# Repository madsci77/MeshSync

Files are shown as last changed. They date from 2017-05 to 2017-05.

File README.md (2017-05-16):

# MeshSync
A simple mobile ad hoc network designed to synchronize EL wire or LEDs on Burning Man costumes

I created this project back in 2012 with the goal of building a low cost device (around USD $10) that would plug in between a user's EL wire inverter and the EL wire on their costume or bike and automatically synchronize flashing patterns with other users around them.

It worked pretty well, but it turned out to be nearly impossible to get enough people together at the same time to do any of the more elaborate patterns.  Around 40 units were built.

Also included is a visual simulator written in VB to test out various aspects of the protocol.  It supports automatic partitioning and merging; if a group splits or multiple groups come together, they will automatically reorganize.  Patterns are chosen that are appropriate for the number of group members.

It's a mesh network and in the pathological case of nodes strung out so that each can only hear one node to either side, it'll still converge within a few network cycles.

Very little data is carried over the network; it's just timing information, group membership, and the currently running pattern.

The lowest hardware ID chooses the pattern.  Hardware ID 0 is reserved for a manual control device with a selector button.  Absent a manual control, patterns are chosen randomly.

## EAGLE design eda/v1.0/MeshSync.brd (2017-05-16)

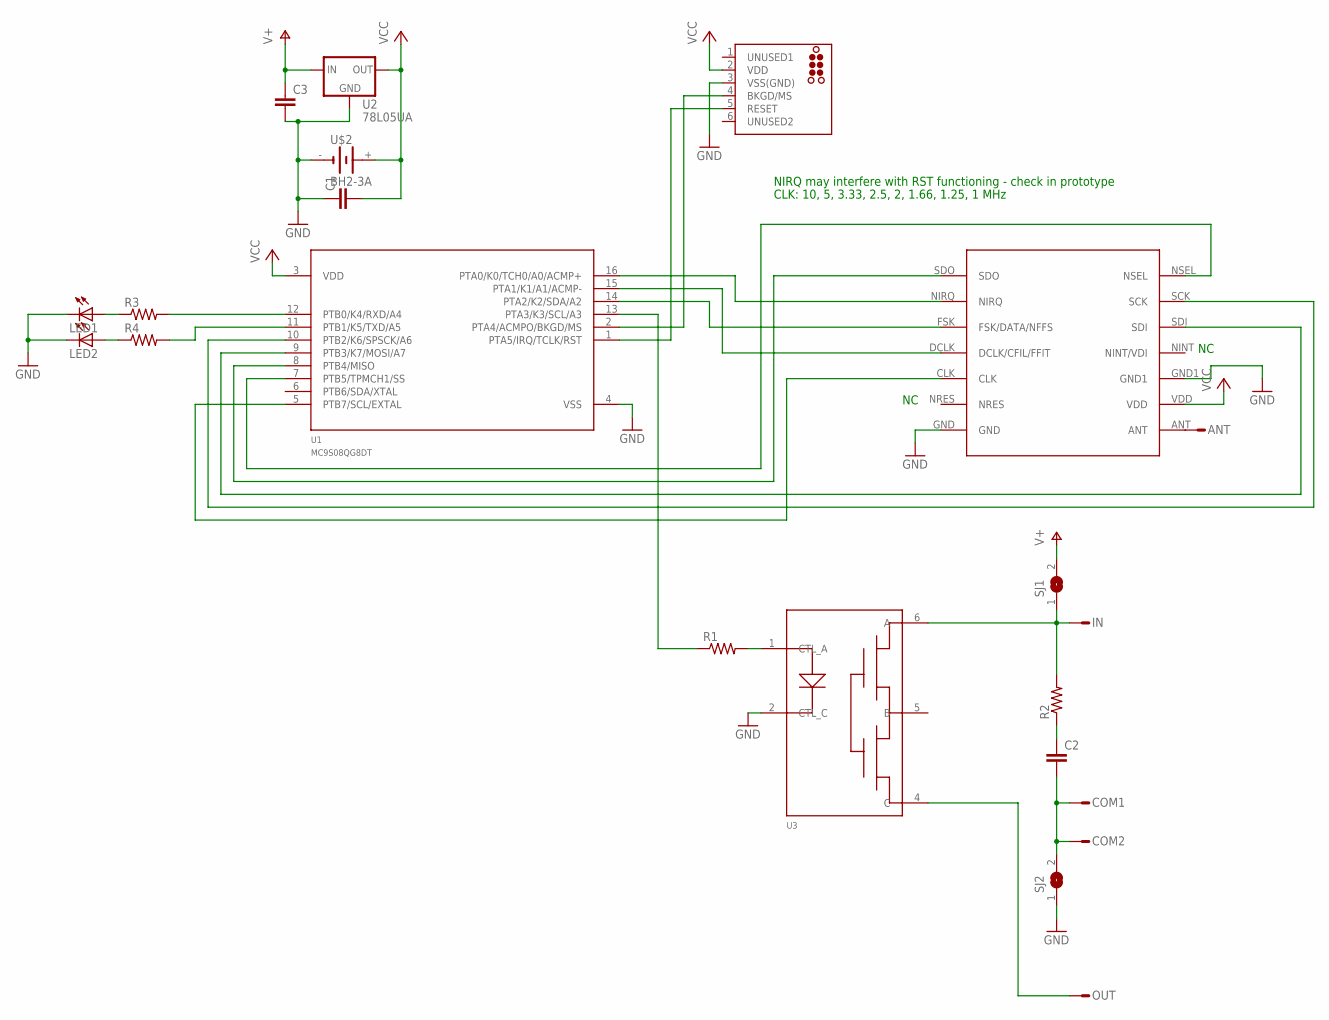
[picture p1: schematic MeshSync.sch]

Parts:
ANT: PIN; PINHEAD-1
C1: C-EUC0805K; C0805K
C2, C3: C-EUC0603K; C0603K
COM1, COM2: PIN; PINHEAD-1
IN: PIN; PINHEAD-1
LED1, LED2: LEDCHIPLED_0603; CHIPLED_0603
OUT: PIN; PINHEAD-1
R1, R2, R3, R4: R0603
SJ1, SJ2: SJW
U1: MC9S08QG8DT; TSSOP16
U2: 78L05UA; SOT89
U3: PVT312; DIL06-SMT
U$1: TC2030-MCP-NL
U$2: BH2-3A
XCVR: RFM12B

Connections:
GND: C1.1, C3.2, LED1.C, LED2.C, SJ2.1, U1.4 (VSS), U2.2 (GND), U3.2 (CTL_C), U$1.3 (VSS(GND)), U$2.-, XCVR.GND, XCVR.GND1
unnamed: U1.2 (PTA4/ACMPO/BKGD/MS), U$1.4 (BKGD/MS)
unnamed: U1.1 (PTA5/IRQ/TCLK/RST), U$1.5 (RESET)
unnamed: R1.2, U3.1 (CTL_A)
unnamed: U1.8 (PTB4/MISO), XCVR.SDO
unnamed: U1.9 (PTB3/K7/MOSI/A7), XCVR.SDI
unnamed: U1.10 (PTB2/K6/SPSCK/A6), XCVR.SCK
unnamed: U1.7 (PTB5/TPMCH1/SS), XCVR.NSEL
unnamed: U1.16 (PTA0/K0/TCH0/A0/ACMP+), XCVR.NIRQ
unnamed: U1.5 (PTB7/SCL/EXTAL), XCVR.CLK
unnamed: U1.15 (PTA1/K1/A1/ACMP-), XCVR.DCLK (DCLK/CFIL/FFIT)
unnamed: U1.14 (PTA2/K2/SDA/A2), XCVR.FSK (FSK/DATA/NFFS)
unnamed: ANT.1, XCVR.ANT
unnamed: R1.1, U1.13 (PTA3/K3/SCL/A3)
unnamed: IN.1, R2.2, SJ1.1, U3.6 (A)
unnamed: OUT.1, U3.4 (C)
unnamed: C2.1, R2.1
unnamed: C2.2, COM1.1, COM2.1, SJ2.2
unnamed: R4.2, U1.11 (PTB1/K5/TXD/A5)
unnamed: R3.2, U1.12 (PTB0/K4/RXD/A4)
unnamed: LED1.A, R3.1
unnamed: LED2.A, R4.1
V+: C3.1, SJ1.2, U2.3 (IN)
VCC: C1.2, U1.3 (VDD), U2.1 (OUT), U$1.2 (VDD), U$2.+, XCVR.VDD

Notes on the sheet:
CLK: 10, 5, 3.33, 2.5, 2, 1.66, 1.25, 1 MHz
NIRQ may interfere with RST functioning - check in prototype

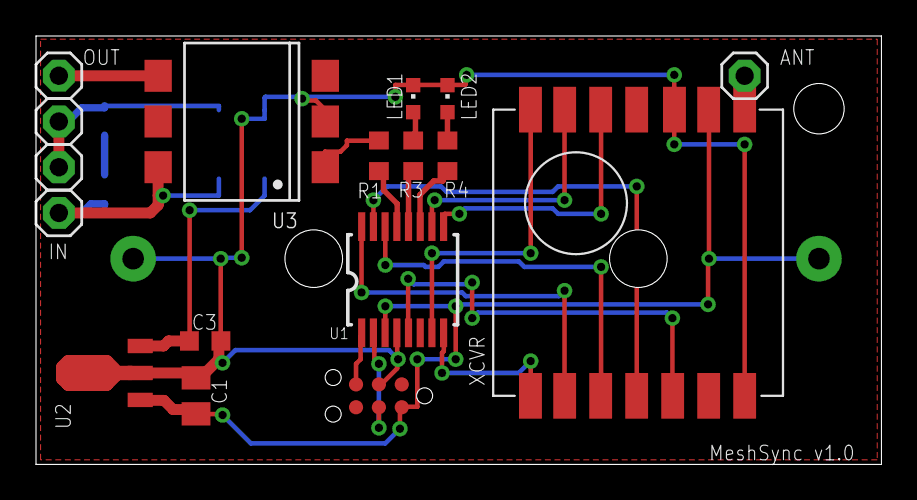
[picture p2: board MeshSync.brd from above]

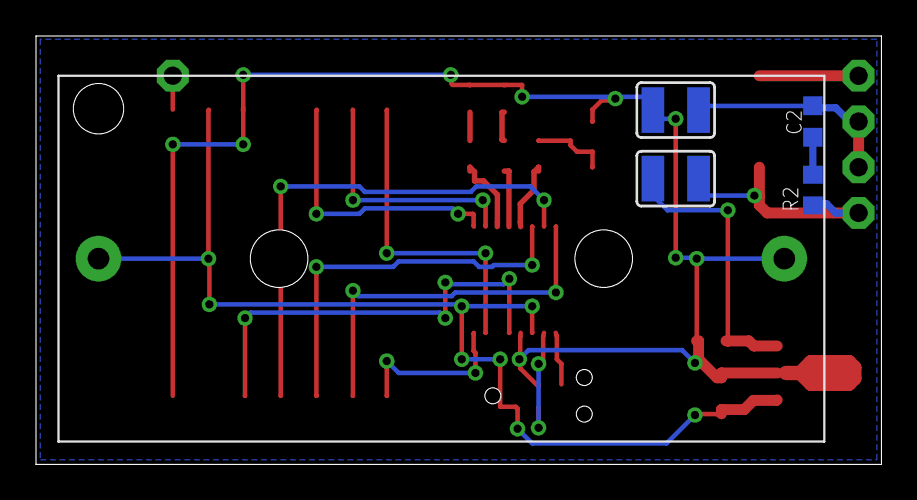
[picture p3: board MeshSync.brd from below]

Board: 2 copper layers, 47.0 x 23.8 mm, 22 parts (5 on the bottom side), 24 nets.

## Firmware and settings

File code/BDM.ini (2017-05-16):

[HI-WAVE]
Target=HCS08ICDCYCLMULT
CPU=HCS08
MainFrame=2,3,-1,-1,-1,-1,154,154,1594,925
TOOLBAR=57600 57601 32795 0 57635 57634 57637 0 57671 57669 0 32777 32776 32782 32780 32781 32778 0 32806
Configuration=BDM.hwc
Layout=BDM.hwl
Statusbar=1
ShowToolbar=1
Smallborder=0
Hideheadline=0
Hidetitle=0










[HCS08ICDCYCLMULT]
SHOWPROT=0
CMDFILE0=CMDFILE STARTUP ON "startup.cmd"
CMDFILE1=CMDFILE RESET ON "reset.cmd"
CMDFILE2=CMDFILE PRELOAD ON "preload.cmd"
CMDFILE3=CMDFILE POSTLOAD ON "postload.cmd"
HCS08DBGMODULEADR=0x1810
DBG0=DBG GENERAL DISARM_ON PROTECT_OFF ANALYZE_ON STEPATRUN_ON
DBG1=DBG PREDEFINED SELECT 0
DBG2=DBG PREDEFINED DBGENGINE END STOP 0x0
DBG3=DBG USER 0x0 0x0






[DEVICE]
CHIPMODE=9S08QG8

[9S08AW16A]
PROGRAMMING_ALGORITHM=0
DOTRIM=1
PRESERVE1_START=0
PRESERVE1_END=0
PRESERVE1_ACTIVE=0
PRESERVE2_START=0
PRESERVE2_END=0
PRESERVE2_ACTIVE=0
PRESERVE3_START=0
PRESERVE3_END=0
PRESERVE3_ACTIVE=0
PRESERVE_EEPROM=0
CUSTOM_TRIM=0
NGS_TRIM_OVERRIDE_REFERENCE_FREQUENCY=24300000
ALTERNATIVE_ALGORITHM_PATH=
ALTERNATIVE_ALGORITHM_CHECKBOX=0

[SETTINGS]
DEFAULT_SOURCE_PATH=C:\Program Files\Freescale\CodeWarrior for Microcontrollers V6.2\prog
MEMORYSTART1=0
MEMORYSTART2=0



[STARTUP12]
show_hstep_assembly_details=0

[STARTUP]
CPUTARGETTYPE=0
IO_DELAY_SET=0
USE_CYCLONEPRO_RELAYS=1
CyclonePro_poweroffonexit=0
CyclonePro_currentvoltage=128
CyclonePro_PowerDownDelay=250
CyclonePro_PowerUpDelay=250
IO_DELAY_CNT=24
PCI_DELAY=0
RESET_DELAY=0
PORT=101
interface_selection=4
SHOWDIALOG=0


[PORT]
IP=

[HCS08]
FILE1=
BINTORAM=1
BINTOFLASH=0
GOTILMAIN=0
KEEPCPROGOPEN=0

[SAVESETTINGS]
S19FILENAME=
PRGFILENAME=
PRGFILEPATH=C:\Program Files\Freescale\CodeWarrior for Microcontrollers V6.2\prog
SERIALFILENAME=

[PEDEBUG]
CURRENTDEVICE=9S08QG8
CURRENTMODE=4
ASK_BEFORE_ERASING_FLASH=0
AUTO_SYNC=1

[9S08AW60]
PROGRAMMING_ALGORITHM=0
DOTRIM=1
PRESERVE1_START=0
PRESERVE1_END=0
PRESERVE1_ACTIVE=0
PRESERVE2_START=0
PRESERVE2_END=0
PRESERVE2_ACTIVE=0
PRESERVE3_START=0
PRESERVE3_END=0
PRESERVE3_ACTIVE=0
PRESERVE_EEPROM=0
CUSTOM_TRIM=0
NGS_TRIM_OVERRIDE_REFERENCE_FREQUENCY=24300000
ALTERNATIVE_ALGORITHM_PATH=
ALTERNATIVE_ALGORITHM_CHECKBOX=0


[Recent Applications File List]
File0=S:\source-private\MeshSync\trunk\bin\MeshSync
File1=S:\source-private\MeshSync\trunk\bin\MeshSync.s19
File2=S:\source\Tracker2\trunk\bin\otusb
File3=S:\source\Tracker2\trunk\bin\ot1usb
LoadFlags0=NORUNAFTERLOAD
LoadFlags1=NORUNAFTERLOAD
LoadFlags2=NORUNAFTERLOAD
LoadFlags3=NORUNAFTERLOAD

[9S08JM60]
PROGRAMMING_ALGORITHM=0
DOTRIM=1
PRESERVE1_START=0
PRESERVE1_END=0
PRESERVE1_ACTIVE=0
PRESERVE2_START=0
PRESERVE2_END=0
PRESERVE2_ACTIVE=0
PRESERVE3_START=0
PRESERVE3_END=0
PRESERVE3_ACTIVE=0
PRESERVE_EEPROM=0
CUSTOM_TRIM=0
NGS_TRIM_OVERRIDE_REFERENCE_FREQUENCY=3125000
ALTERNATIVE_ALGORITHM_PATH=
ALTERNATIVE_ALGORITHM_CHECKBOX=0


[Recent Layout File List]
File0=BDM.hwl
File1=
File2=
File3=

[Recent HI-WAVE FindProcedure Search]
Search0=cmd_txinterval
Search1=swihandler
Search2=system_reset

[9S08QG8]
PROGRAMMING_ALGORITHM=0
DOTRIM=1
PRESERVE1_START=0
PRESERVE1_END=0
PRESERVE1_ACTIVE=0
PRESERVE2_START=0
PRESERVE2_END=0
PRESERVE2_ACTIVE=0
PRESERVE3_START=0
PRESERVE3_END=0
PRESERVE3_ACTIVE=0
PRESERVE_EEPROM=0
CUSTOM_TRIM=0
NGS_TRIM_OVERRIDE_REFERENCE_FREQUENCY=3125000
ALTERNATIVE_ALGORITHM_PATH=
ALTERNATIVE_ALGORITHM_CHECKBOX=0

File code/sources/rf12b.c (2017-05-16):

// RF12B transceiver support code

#include "hardware.h"
#include "utility.h"
#include "rf12b.h"
#include "events.h"
#include "string.h"
#include "meshsync.h"

#define FEND 0xC0
#define FESC 0xDB
#define TFEND 0xDC
#define TFESC 0xDD

//#define USE_HAMMING

#define RX_BUFFER_SIZE 64
#define MIN_PACKET_SIZE 4

//unsigned char *tx_next_packet, *tx_head, *tx_tail, txbyte;
unsigned char rx_buffer[RX_BUFFER_SIZE];

#define PTT_ON {spi16(0x8228); spi16(0x8238);}
#define PTT_OFF {spi16(0x8228); spi16(0x82d8);}

volatile static unsigned short fcs, txcount;
volatile static unsigned char rxcount;
static char escape;

unsigned short crc_calc(unsigned char c, unsigned short f)
{
	unsigned char bit;
	for (bit=8; bit; bit--)
	{
		if ((f ^ c) & 1) f = (f >> 1) ^ 0x8408;
		else f = f >> 1;
		c = c >> 1;
	}
	return f;
}


// Hamming ECC codeword table, encode most significant nybble first
const unsigned char hamming_codeword[16] = {
	0b00000000,	0b01010001,	0b01110010,	0b00100011,	0b00110100,	0b01100101,	0b01000110,	0b00010111,
	0b01101000,	0b00111001,	0b00011010,	0b01001011,	0b01011100,	0b00001101,	0b00101110,	0b01111111
};

// Transposed table for decoding
const unsigned char hamming_transpose[3] = {
	0b01001011,	0b00101110,	0b00010111
};

const unsigned char coset[3] = {
	0b00000100,	0b00000010,	0b00000001
};

const unsigned char coset2[8] = {
	0b00000000,	0b00010000,	0b00100000,	0b00000100,	0b01000000,	0b00000001,	0b00001000,	0b00000010
};

unsigned char tx_interleave[8];
unsigned char rx_interleave[8];
unsigned char tx_i_cnt, rx_i_cnt;

void rf12b_send_raw(unsigned char c);
void rf12b_send(unsigned char c);
void rf12b_interrupt(void);


// Starts packet
void rf12b_start_tx(void)
{
	fcs = 0xffff;
	PTT_ON;
	// Send preamble without Hamming encoding, low effective baud rate for AFC adjustment time
	rf12b_send_raw(0x0f);
	rf12b_send_raw(0x0f);
	rf12b_send_raw(0x0f);
	rf12b_send_raw(0x0f);
	rf12b_send_raw(0x0f);
	rf12b_send_raw(0x0f);
	rf12b_send_raw(0xaa);
	rf12b_send_raw(0xaa);	
	rf12b_send_raw(0x2d);
	rf12b_send_raw(0xd4);
	tx_i_cnt = 0;		// Reset interleave buffer count
}

// Ends packet
void rf12b_end_tx(void)
{
	fcs ^= 0xffff;	

//FIXME: this won't handle CRCs that come out to escape sequences
	rf12b_send(fcs & 0xff);
	rf12b_send(fcs >> 8);
	rf12b_send(FEND);
	rf12b_send(FEND);
	rf12b_send(FEND);
	rf12b_send(FEND);
	// Pad interleaving matrix with FEND characters
#ifdef USE_HAMMING
	while (tx_i_cnt) 	rf12b_send(FEND);
#endif
	while (spi_poll() == 0) reset_watchdog;

	PTT_OFF;
}


// Transmit data without interleaving or Hamming encoding
void rf12b_send_raw(unsigned char c)
{
//	while (spi_poll() == 0) reset_watchdog;
	// Wait for SDO to go high
	SPSCK_LOW;
	SS_LOW;
	SPIC1 = 0b00010000; // Disable SPI
	while (!MISO);
	SPIC1 = 0b01010000; // Enable SPI
	spi16(0xb800 | c);
}


// Send with interleaving and Hamming encoding
void rf12b_send(unsigned char c)
{
#ifdef USE_HAMMING
	// Look up Hamming codewords and add to interleave matrix
	tx_interleave[tx_i_cnt++] = hamming_codeword[c >> 4];
	tx_interleave[tx_i_cnt++] = hamming_codeword[c & 0x0f];
	if (tx_i_cnt == 8)
	{
		unsigned char n;
		// We have 8 codewords to be transmitted (7 bits each)
		for (n = 0; n < 7; n++)
		{
			c = 0;
			for (tx_i_cnt = 0; tx_i_cnt < 8; tx_i_cnt++)
			{
				c <<= 1;
				if (tx_interleave[tx_i_cnt] & 0x40) c |= 1;
				tx_interleave[tx_i_cnt] <<= 1;
			}
			// 7 bytes get sent
			rf12b_send_raw(c);
		}
		tx_i_cnt = 0;
	}
#else
	rf12b_send_raw(c);
#endif
}

#pragma inline
unsigned char rf12b_read(void)
{
	char c;
	SS_LOW;
	// Read and discard 16 bits
	while (!(SPIS & 0x20));
	SPID = 0;
	while (!(SPIS & 0x80));
	c = SPID;
	while (!(SPIS & 0x20));
	SPID = 0;
	while (!(SPIS & 0x80));
	c = SPID;
	// Get FIFO data
	while (!(SPIS & 0x20));
	SPID = 0;
	// Wait for receiver full
	while (!(SPIS & 0x80));
	c = SPID;
	SS_HI;
	return c;
}

void rf12b_rx_fifo_reset(void)
{
	spi16(CMD_FIFO_MODE);				// FIFO interrupt level, sync pattern, start on sync word
	spi16(CMD_FIFO_MODE | FIFO_FF | FIFO_DR);		// Enable FIFO fill
	rx_i_cnt = 0;
	rxcount = 0;
	escape = 0;
}

void rf12b_init(void)
{
	tx_i_cnt = 0;		// Reset interleave buffer count
	rx_i_cnt = 0;
	rf12b_read();
//	spi16(CMD_CONFIG | CONFIG_EF | CONFIG_EL | CONFIG_BAND_915);		// 915 MHz mode (use 80d8 for 433), enable TX register, enable RX FIFO, 12.5 pF caps


// Test with FIFO disabled
	spi16(CMD_CONFIG | CONFIG_EL | CONFIG_BAND_915);		// 915 MHz mode (use 80d8 for 433), enable TX register, enable RX FIFO, 12.5 pF caps

	
	spi16(CMD_POWER | POWER_ER | POWER_EBB | POWER_ES | POWER_EX);		// Enable crystal oscillator + RX and MCU clock output
	
	// Low 12 bits set frequency. Base is 900 MHz, tuning steps are 7.5 kHz
	spi16(CMD_FREQUENCY + ((915000000 - 900000000) / 7500));				// Set frequency to 915 MHz
	spi16(0xcc77);		// MCU clock speed, dithering disabled, PLL bandwidth

//	spi16(CMD_DATA_RATE | DATA_RATE_57600);									// Set data rate
//	spi16(CMD_RX_CTL | RX_BW_134K | RX_GAIN_0 | RX_RSSI_103);			// Fast VDI response, set baseband bandwidth, gain 0, threshold -103 dBm
//	spi16(CMD_TX_CTL | TX_DEV_90K | TX_POWER_0);								// 90 kHz deviation, power 0 dB
/*
	// Production MeshSync
	spi16(CMD_DATA_RATE | DATA_RATE_38400);									// Set data rate
	spi16(CMD_RX_CTL | RX_BW_134K | RX_GAIN_0 | RX_RSSI_103);			// Fast VDI response, set baseband bandwidth, gain 0, threshold -103 dBm
	spi16(CMD_TX_CTL | TX_DEV_90K | TX_POWER_0);								// 90 kHz deviation, power 0 dB
*/
	spi16(CMD_DATA_RATE | DATA_RATE_4800);									// Set data rate
	spi16(CMD_RX_CTL | RX_BW_67K | RX_GAIN_0 | RX_RSSI_103);			// Fast VDI response, set baseband bandwidth, gain 0, threshold -103 dBm
	spi16(CMD_TX_CTL | TX_DEV_45K | TX_POWER_0);								// 90 kHz deviation, power 0 dB


//	spi16(CMD_DATA_FILTER);											// Clock recovery auto-lock disabled, digital filter, DQD threshold

// Analog filter test
	spi16(CMD_ANALOG_FILTER);											// Clock recovery auto-lock disabled, analog filter, DQD threshold


	rf12b_rx_fifo_reset();
	spi16(0xc4f7);		// AFC config
	spi16(0xe000);		// Wake-up timer disabled
	spi16(0xc80e);		// Low duty cycle disabled
	spi16(0xc000);		// Low battery threshold 2.2v, MCU clock 1 MHz
//	spi16(0xc0e0);		// Low battery threshold 2.2v, MCU clock 10 MHz
	wait(2);
	escape = 0;
	rxcount = 0;
//	*(unsigned short*)tx_next_packet = 0;						// Clear next buffer size
}

// Hamming decode - multiplies by transposed table to find syndrome and corrects
unsigned char hamming_decode(unsigned char codeword)
{
	unsigned char col, syndrome, c, parity, bit;

	for (col = 0, syndrome = 0; col < 3; col++)
	{
		c = hamming_transpose[col] & codeword;
		parity = 0;
		for (bit = 0; bit < 8; bit++)
		{
			if (c & 0x80) parity ^= 0xff;
			c <<= 1;
		}
		if (parity)
		{
			// Syndrome is non-zero
			syndrome |= coset[col];
		}
	}
	c = codeword ^ coset2[syndrome];			// Correct modified bit
	return c & 0x0f;
}
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

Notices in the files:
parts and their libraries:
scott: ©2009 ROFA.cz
